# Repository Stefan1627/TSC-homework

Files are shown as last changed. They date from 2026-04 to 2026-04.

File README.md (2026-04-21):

# TSC-homework - Stefan Calmac 334CC
# InkTime Watch

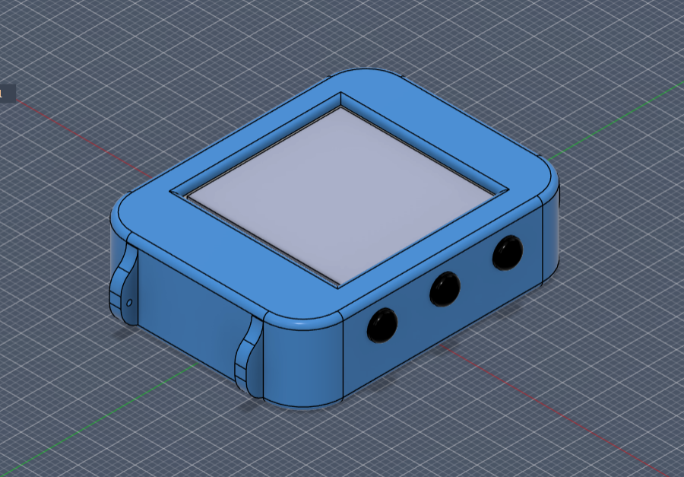
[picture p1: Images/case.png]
InkTime Watch 3D Render


---

## Block Diagram

```
           [ USB Type-C ]                              [ LiPo Battery (250mAh) ]
                 | 5V VBUS                                      |
                 v                                              |
          +---------------+                                     |
          |               | BAT                                 |
          |    BQ25180    |<------------------------------------+
          | (Charger IC)  |                                     |
          +---------------+                                     v
                 | VSYS                                 +---------------+
                 v                                      |   MAX17048    |
          +---------------+                             | (Fuel Gauge)  |
          |    RT6160     |                             +---------------+
          | (Buck-Boost)  |                                     ^
          +---------------+                                     |
                 | 3.3V System Rail (VDD_3V3)                   |
                 |                                              |
 +---------------+----------------------------------------------+-----+
 |               |                                              |     |
 |               v                                              |     |
 |        +-------------+         I2C Bus                       |     |
 |        |             |<======================================+     |
 |        |             |                                             |
 |        |             |=== I2C ===> [ BMA421 Accelerometer ]        |
 |        |  nRF52840   |                                             |
 |        |    MCU      |=== I2C ===> [ DRV2605L Driver ]-->[ Motor ] |
 |        |             |                                             |
 |        |             |=== SPI ===> [ 1.54" E-paper Display ]       |
 |        |             |                       ^                     |
 |        |             |-- GPIO (Gate)         | VEPD (Switched Pwr) |
 |        +-------------+      |                |                     |
 |          ^  ^  ^  |         v                |                     |
 |          |  |  |  | +---------------+        |                     |
 +---------(|--|--|)-+-|  PFET Switch  |--------+                     |
            |  |  |  | +---------------+                              |
 [Up]-------+  |  |  |                                                |
           [Down] |  +--- [ 2.4GHz Antenna ] - - - BLE - - - [ Companion ]
                  |                                          [   Phone   ]
              [Enter/Esc]
```

---

## Bill of Materials (BOM)

Below is the list of primary active and critical passive components used in this
design. Links are provided to JLCPCB parts (LCSC) and standard datasheets.

| Component / Module | Description | Package / Footprint | Part | Datasheet Link |
:--- | :--- | :--- | :--- | :--- |
| **nRF52840** | Multi-protocol BLE 5.0 Cortex-M4F MCU | AQFN-73 | [C190794](https://jlcpcb.com/partdetail/NordicSemicon-NRF52840_QIAAR/C190794) | [Nordic nRF52840](https://www.nordicsemi.com/Products/nRF52840) |
| **BQ25180YBGR** | I2C Controlled 1A Linear LiPo Charger | DSBGA-8 | [BQ25180YBGR](https://www.ti.com/product/BQ25180/part-details/BQ25180YBGR) | [TI BQ25180](https://www.ti.com/product/BQ25180) |
| **MAX17048G+T10** | Micropower 1-Cell Fuel Gauge | TDFN-8 | [C2682616](https://www.lcsc.com/product-detail/C2682616.html) | [Maxim MAX17048](https://www.analog.com/en/products/max17048.html) |
| **RT6160AWSC** | High-Efficiency Buck-Boost Converter (3.3V) | WLCSP-15 | [C7065276](https://www.lcsc.com/product-detail/C7065276.html) | [Richtek RT6160A](https://www.richtek.com/assets/product_file/RT6160A/DS6160A-02.pdf) |
| **BMA421** | Ultra-Low Power IMU / Step Counter | LGA-12 | [C5242966](https://jlcpcb.com/partdetail/BoschSensortec-BMA421/C5242966) | [Bosch BMA421](https://www.bosch-sensortec.com/products/motion-sensors/imus/bma421/) |
| **DRV2605YZFR** | Haptic Driver for LRA/ERM | DSBGA-9 | [C527464](https://jlcpcb.com/partdetail/C527464) | [TI DRV2605](https://www.ti.com/product/DRV2605) |
| **2450AT18B100E** | 2.4GHz Chip Antenna | 1206 | [C2917717](https://jlcpcb.com/partdetail/JohansonDielectrics-2450AT18B100E/C2917717) | [Johanson 2450AT18B100E](https://www.johansontechnology.com/datasheets/antennas/2450AT18B100.pdf) |
| **USBLC6-2SC6Y** | Very low capacitance ESD protection | SOT-23-6 | [C2969755](https://jlcpcb.com/partdetail/STMicroelectronics-USBLC62SC6Y/C2969755) | [ST USBLC6-2](https://www.st.com/resource/en/datasheet/usblc6-2.pdf) |
| **KH-TYPE-C-16P** | USB Type-C 16-Pin Receptacle | SMD | [C168704](https://jlcpcb.com/partdetail/180087-918418K2022Y40000/C168704) | [Generic USB-C](https://datasheet.lcsc.com/lcsc/1811151641_Korean-Hroparts-Elec-TYPE-C-31-M-12_C165948.pdf) |
| **503480-2400** | 24-Pin FPC Connector (0.5mm pitch) for EPD | SMD |  | [Molex 503480](https://www.molex.com/molex/products/part-detail/ffc_fpc_connectors/5034802400) |
| **DMG2305UX** | P-Channel MOSFET (EPD Power Control) | SOT-23 | [C2940629](https://jlcpcb.com/partdetail/TECHPUBLIC-DMG2305UX/C2940629) | [Diodes DMG2305](https://www.diodes.com/assets/Datasheets/DMG2305UX.pdf) |
| **MBR0530** | Schottky Diode (E-Paper Pump Circuit) | SOD-123 | [C77336](https://jlcpcb.com/partdetail/78464-MBR0530/C77336) | [Onsemi MBR0530](https://www.onsemi.com/pdf/datasheet/mbr0530t1-d.pdf) |
| **TC2030-IDC** | 6-Pin Tag-Connect SWD Interface | PCB Footprint | [Tag-Connect](https://www.tag-connect.com/product/tc2030-idc-nl) | [Tag-Connect TC2030](https://www.tag-connect.com/product/tc2030-idc-6-pin-tag-connect-plug-of-nails-spring-pin-cable-with-ribbon-connector) |

### Passive Components

| Component | Value | Package | Qty | Function |
|---|---|---|-----|---|
| Capacitors (decoupling) | 100nF | 0201 | 5 | MCU + peripheral decoupling |
| Capacitors (crystal load) | 12pF | 0201 | 4 | 32MHz + 32.768kHz crystal loads |
| Capacitors (bulk) | 4.7uF | 0402 | 4 | MCU power rail bulk decoupling |
| Capacitors (USB) | 4.7uF | 0402 | 1 | DECUSB capacitor |
| Capacitors (power) | 22uF | 0402 | 2 | RT6160 input capacitors |
| Capacitors (charger) | 1uF | 0402 | 3 | BQ25180 CIN/CSYS/CBAT |
| Capacitors (EPD) | 1uF/50V | 0402 | 9 | E-paper driver capacitors |
| Inductor (DC/DC) | 10uH | 0402 | 1 | nRF52840 REG1 DC/DC inductor |
| Inductor (buck-boost) | 0.47uH | 2012 | 1 | RT6160 power stage inductor |
| Resistors (I2C pull-up) | 10k | 0201 | 2 | I2C SDA/SCL pull-ups |
| Resistors (USB CC) | 5.1k | 0201 | 2 | USB Type-C CC1/CC2 pull-downs |
| Crystals | 32 MHz | 2016 | 1 | HFXO for MCU + radio |
| Crystals | 32.768 kHz | 3215 | 1 | LFXO for RTC timekeeping |

---

## Hardware Description

### MCU - nRF52840

The nRF52840 is the central processing unit of InkTime. It integrates:

- **ARM Cortex-M4F** at 64 MHz with FPU
- **BLE 5.0** (used for time sync, notifications)
- **USB 2.0 Full Speed** (charging detection and firmware updates)
- **1 MB Flash / 256 KB RAM**

All peripherals are connected directly to the nRF52840 via SPI (e-paper display) and I2C (IMU, fuel gauge, haptic driver, PMIC).

### Power Path

```
USB-C --> BQ25180 (charger) --> LiPo battery (AKY0106, 400 mAh)
                            --> 3.3V rail (VREG, for MCU and all peripherals)
Battery --> RT6160AWSC (boost) --> EPD high-voltage supply (VCOM, gate voltages)
```

- **BQ25180YBGR** manages LiPo charging at up to 1A, monitors VBUS, and raises `PMIC_INT` for fault/status events. Communicates with the MCU over I2C.
- **RT6160AWSC** is a boost converter that generates the higher voltages needed by the e-paper display driver (PREVGH, PREVGL, etc.).
- **MAX17048G+T10** is a ModelGauge fuel gauge that estimates battery state-of-charge (SOC) with 1% accuracy over I2C, using a single-cell LiPo model.

### E-Paper Display - WSH-12561

The e-paper display connects to the MCU over **SPI** plus 3 control GPIOs:

| Signal | Direction | Description |
| --- | --- | --- |
| SCK | MCU → EPD | SPI clock |
| MOSI | MCU → EPD | SPI data |
| EPD_CS | MCU → EPD | Chip select (active low) |
| EPD_DC | MCU → EPD | Data / Command select |
| EPD_RST  | MCU → EPD | Hardware reset (active low) |
| EPD_BUSY | EPD → MCU | Busy flag (MCU must wait) |

The EPD drive circuit (biased by RT6160AWSC) generates the voltages PREVGH, PREVGL, PREVGL, GDR necessary to drive the e-paper panel.

### IMU

6-axis inertial measurement unit connected via **I2C** at 400 kHz. Provides:

- 3-axis accelerometer (step counting, gesture detection, orientation)
- 3-axis gyroscope (motion tracking)
- Two interrupt lines (`IMU_INT1`, `IMU_INT2`) for wake-on-motion and data-ready events

### Haptic Feedback - DRV2605 + FIT0774

The DRV2605YZFR haptic driver controls the FIT0774 ERM motor. It connects to the MCU over **I2C** and has a digital enable signal `HAPTIC_EN`. It supports library-based waveform playback (124 built-in effects).

### USB - KH-TYPE-C-16P + USBLC6-2SC6Y

USB-C connector with USBLC6-2SC6Y ESD protection on D+ and D− lines. The MCU detects VBUS presence via a GPIO for charging control handoff. USB D+ / D− connect directly to the nRF52840's USB transceiver.

### Antenna - 2450AT18B100E

2.4 GHz chip antenna placed at the PCB edge, away from metal and ground planes. The PCB is **cutout under the antenna** - no copper pours or signal traces are routed under the antenna keepout area. Impedance matching network (L + C pi filter) is present between the nRF52840 RF pin and the antenna.

### SWD Debug - TC2030-IDC

Tag-Connect TC2030-IDC footprint for in-circuit programming and debugging (no connector needed, uses spring-loaded probe). Test pads TP_SWDIO, TP_SWDCLK, TP_RESET, TP_3.3V, TP_GND are exposed on the PCB silkscreen.

---

## nRF52840 Pinout Specification
The major hardware peripherals are mapped to the MCU as follows:

*   **Shared I2C Bus (with 10k pull-ups to 3.3V):**
    *   `P0.06` - SDA (Data for BMA421, MAX17048, BQ25180, RT6160, DRV2605L).
    *   `P0.07` - SCL (Clock).
*   **SPI Bus (E-paper Display):**
    *   `P0.02` - SCK
    *   `P0.03` - MOSI
    *   `P0.05` - CS (Chip Select)
    *   `P0.15` - DC (Data/Command)
    *   `P0.16` - RST (Reset)
    *   `P0.17` - BUSY (Panel status)
    *   `P1.01` - PFET Gate (Enables/disables the display power rail)
*   **Interrupts & Peripherals:**
    *   `P0.08` - BMA421 INT1 (Primary motion/step wake).
    *   `P1.08` - BMA421 INT2 (Secondary motion events).
    *   `P0.10` - MAX17048 ALRT (Low battery wake).
    *   `P0.11` - BQ25180 /INT (Charger state wake).
    *   `P0.12` - DRV2605L EN (Enable haptics chip).
*   **Physical Buttons (Active-low to GND):**
    *   `P0.13` - Up Button.
    *   `P0.14` - Down Button.
    *   `P1.00` - Enter / Esc Button.
*   **Debug & Clocks:**
    *   `XC1/XC2` & `XL1/XL2` - Connects the 32MHz and 32.768kHz external crystals.
    *   `SWDIO`, `SWDCLK`, `nRESET` - Connected to the Tag-Connect TC2030 debug footprint.

--- 

## PCB Design

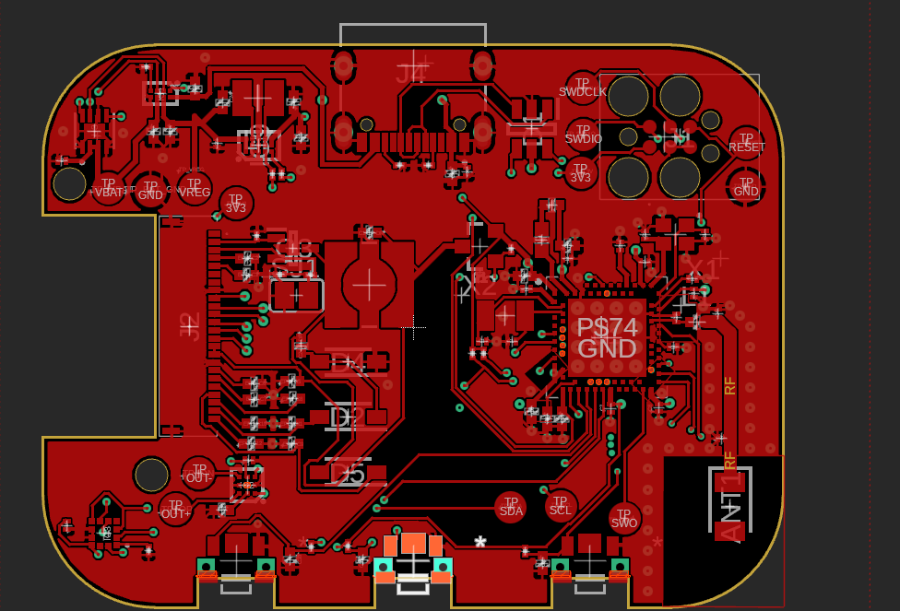
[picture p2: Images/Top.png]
Top layer


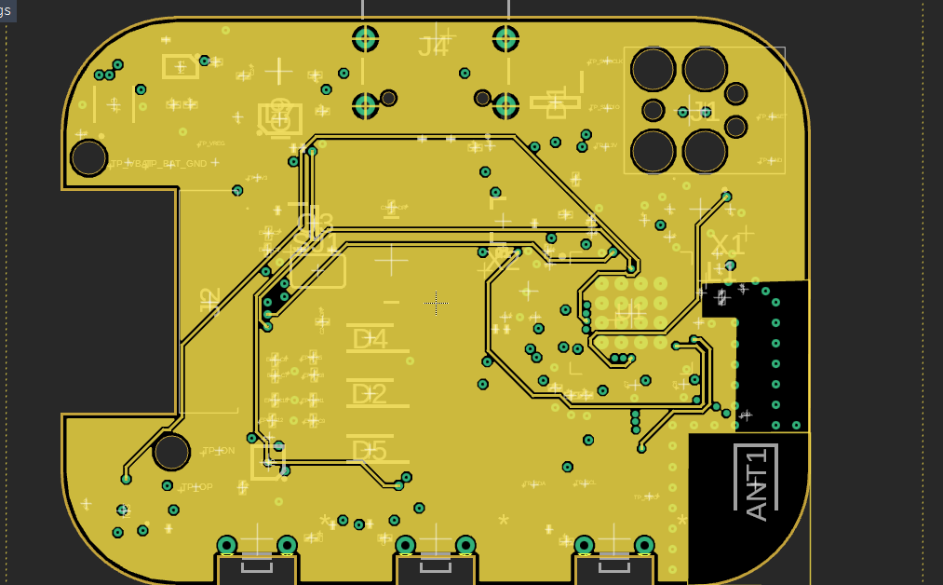
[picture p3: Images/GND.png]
Middle_1 layer


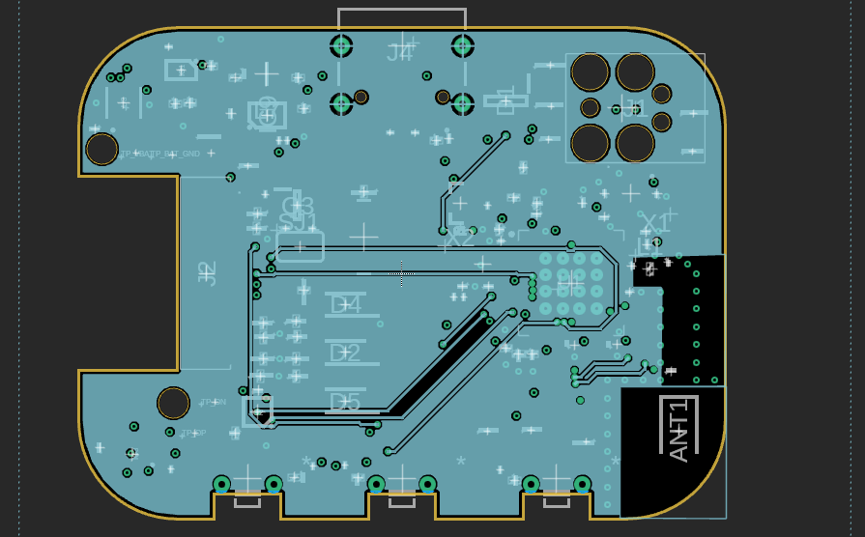
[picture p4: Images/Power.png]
Middle_2 layer


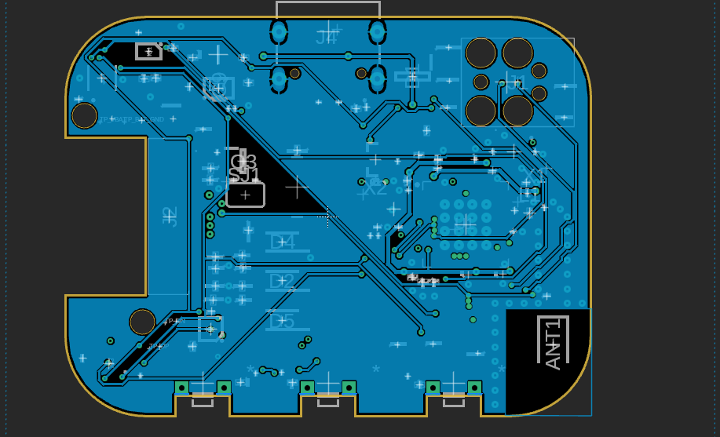
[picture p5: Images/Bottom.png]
Bottom layer


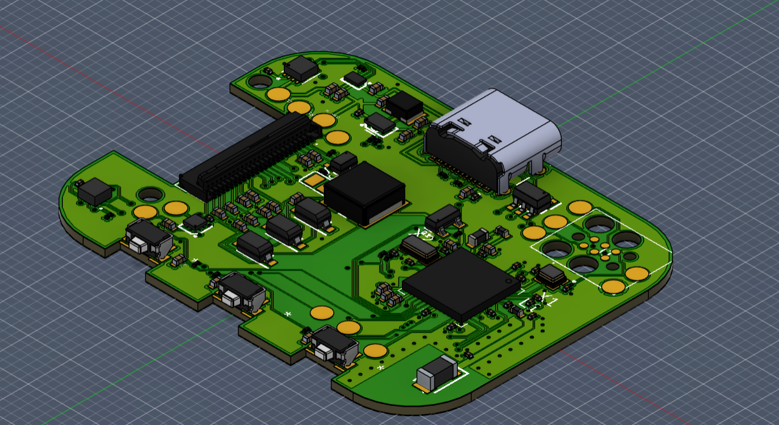
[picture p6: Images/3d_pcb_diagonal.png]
3D Pcb


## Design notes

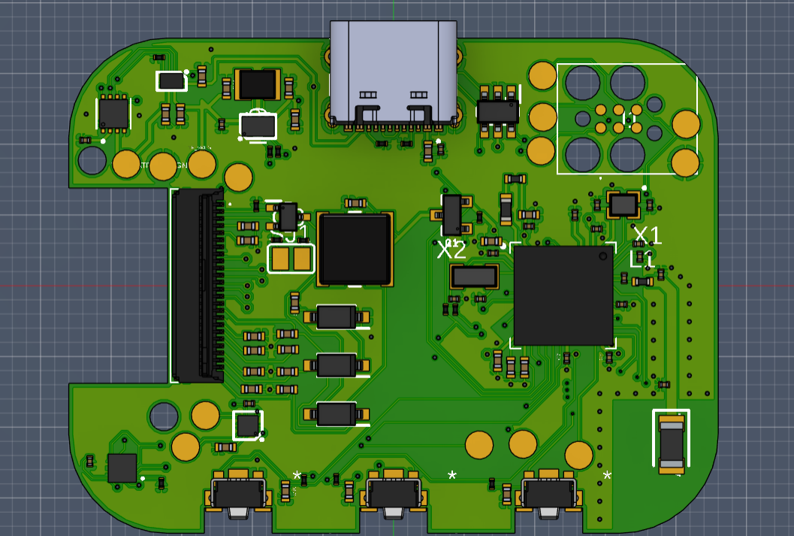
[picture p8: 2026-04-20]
Images/3d_pcb_top.png

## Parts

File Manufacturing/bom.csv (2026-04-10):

Part | Value | Device | Footprint Name | Detailed Description | ARROW_PART_NUMBER | ARROW_PRICE-STOCK | AVAILABILITY | CHECK_PRICES | COPYRIGHT | DESCRIPTION | DIGI-KEY_PART_NUMBER_1 | DIGI-KEY_PART_NUMBER_2 | DIGI-KEY_PART_NUMBER_3 | HEIGHT | JLCPCB | MANUFACTURER_NAME | MANUFACTURER_PART_NUMBER | MF | MFR_NAME | MOUSER_PART_NUMBER | MOUSER_PRICE-STOCK | MP | PACKAGE | POPULARITY | PRICE | PROD_ID | PURCHASE-URL | SNAPEDA_LINK | TP_SIGNAL_NAME | VALUE
ANT1 | 2450AT18B100E | 2450AT18B100E_2450AT18B100E | 2450AT18B100E_ANTC3216X140N | Antennas 2.45GHz ANTENNA | 2450AT18B100E | https://www.arrow.com/en/products/2450at18b100e/johanson-dielectrics?utm_currency=USD&region=nac |  |  |  | Antennas 2.45GHz ANTENNA |  |  |  | 1.4mm |  | JOHANSON TECHNOLOGY | 2450AT18B100E |  |  | 609-2450AT18B100E | https://www.mouser.co.uk/ProductDetail/Johanson-Technology/2450AT18B100E?qs=yCnrNFeXz%252Bh5MFsFIXGZGA%3D%3D
C1 | 12pF | NORDIC_NRF_3_CAPACITOR_0201_L | NORDIC_NRF_3_RESC0201_L | Generic chip capacitor
C1-EP-DR | 10uF | NORDIC_NRF_3_CAPACITOR_0402_L | NORDIC_NRF_3_RESC0402_L | Generic chip capacitor
C2-EP-DR | 4.7uF/25V | NORDIC_NRF_3_CAPACITOR_0402_L | NORDIC_NRF_3_RESC0402_L | Generic chip capacitor
C3 | 1pF | NORDIC_NRF_3_CAPACITOR_0201_L | NORDIC_NRF_3_RESC0201_L | Generic chip capacitor
C4 | 1pF | NORDIC_NRF_3_CAPACITOR_0201_L | NORDIC_NRF_3_RESC0201_L | Generic chip capacitor
C5 | 100nF | NORDIC_NRF_3_CAPACITOR_0201_L | NORDIC_NRF_3_RESC0201_L | Generic chip capacitor
C6 | 4.7uF | NORDIC_NRF_3_CAPACITOR_0402_L | NORDIC_NRF_3_RESC0402_L | Generic chip capacitor
C7 | 100nF | NORDIC_NRF_3_CAPACITOR_0201_L | NORDIC_NRF_3_RESC0201_L | Generic chip capacitor
C8 | 100nF | NORDIC_NRF_3_CAPACITOR_0201_L | NORDIC_NRF_3_RESC0201_L | Generic chip capacitor
C9 | 820pF | NORDIC_NRF_3_CAPACITOR_0201_L | NORDIC_NRF_3_RESC0201_L | Generic chip capacitor
C10 | N.C. | NORDIC_NRF_3_CAPACITOR_0201_L | NORDIC_NRF_3_RESC0201_L | Generic chip capacitor
C11 | 100pF | NORDIC_NRF_3_CAPACITOR_0201_L | NORDIC_NRF_3_RESC0201_L | Generic chip capacitor
C12 | 100nF | NORDIC_NRF_3_CAPACITOR_0201_L | NORDIC_NRF_3_RESC0201_L | Generic chip capacitor
C13 | N.C. | NORDIC_NRF_3_CAPACITOR_0201_L | NORDIC_NRF_3_RESC0201_L | Generic chip capacitor
C14 | 4.7uF | NORDIC_NRF_3_CAPACITOR_0402_L | NORDIC_NRF_3_RESC0402_L | Generic chip capacitor
C15 | 1.0uF | NORDIC_NRF_3_CAPACITOR_0402_L | NORDIC_NRF_3_RESC0402_L | Generic chip capacitor
C16 | 47nF | NORDIC_NRF_3_CAPACITOR_0201_L | NORDIC_NRF_3_RESC0201_L | Generic chip capacitor
C17 | 12pF | NORDIC_NRF_3_CAPACITOR_0201_L | NORDIC_NRF_3_RESC0201_L | Generic chip capacitor
C18 | 12pF | NORDIC_NRF_3_CAPACITOR_0201_L | NORDIC_NRF_3_RESC0201_L | Generic chip capacitor
C19 | 100nF | NORDIC_NRF_3_CAPACITOR_0201_L | NORDIC_NRF_3_RESC0201_L | Generic chip capacitor
C20\ | 4.7uF | NORDIC_NRF_3_CAPACITOR_0402_L | NORDIC_NRF_3_RESC0402_L | Generic chip capacitor
C21 | 4.7uF | NORDIC_NRF_3_CAPACITOR_0402_L | NORDIC_NRF_3_RESC0402_L | Generic chip capacitor
C22 | N.C. | NORDIC_NRF_3_CAPACITOR_0201_L | NORDIC_NRF_3_RESC0201_L | Generic chip capacitor
C23 | 0.1uF | NORDIC_NRF_3_CAPACITOR_0201_L | NORDIC_NRF_3_RESC0201_L | Generic chip capacitor
C24 | 10uF | NORDIC_NRF_3_CAPACITOR_0402_L | NORDIC_NRF_3_RESC0402_L | Generic chip capacitor
C25 | 22uF | NORDIC_NRF_3_CAPACITOR_0402_L | NORDIC_NRF_3_RESC0402_L | Generic chip capacitor
C27 | 0.1uF | NORDIC_NRF_3_CAPACITOR_0201_L | NORDIC_NRF_3_RESC0201_L | Generic chip capacitor
C29 | 1uF | NORDIC_NRF_3_CAPACITOR_0402_L | NORDIC_NRF_3_RESC0402_L | Generic chip capacitor
C30 | 1uF | NORDIC_NRF_3_CAPACITOR_0402_L | NORDIC_NRF_3_RESC0402_L | Generic chip capacitor
C31 | 1uF | NORDIC_NRF_3_CAPACITOR_0402_L | NORDIC_NRF_3_RESC0402_L | Generic chip capacitor
C32 | 1uF | NORDIC_NRF_3_CAPACITOR_0402_L | NORDIC_NRF_3_RESC0402_L | Generic chip capacitor
C33 | 22uF | NORDIC_NRF_3_CAPACITOR_0402_L | NORDIC_NRF_3_RESC0402_L | Generic chip capacitor
C34 | 0.1uF | NORDIC_NRF_3_CAPACITOR_0201_L | NORDIC_NRF_3_RESC0201_L | Generic chip capacitor
C37 | 1uF | NORDIC_NRF_3_CAPACITOR_0402_L | NORDIC_NRF_3_RESC0402_L | Generic chip capacitor
C38 | 1uF | NORDIC_NRF_3_CAPACITOR_0402_L | NORDIC_NRF_3_RESC0402_L | Generic chip capacitor
C39 | 10uF | NORDIC_NRF_3_CAPACITOR_0402_L | NORDIC_NRF_3_RESC0402_L | Generic chip capacitor
C42 | 0.1uF | NORDIC_NRF_3_CAPACITOR_0201_L | NORDIC_NRF_3_RESC0201_L | Generic chip capacitor
C43 | 4.7uF | NORDIC_NRF_3_CAPACITOR_0402_L | NORDIC_NRF_3_RESC0402_L | Generic chip capacitor
D1 | USBLC6-2SC6Y | USBLC6-2SC6Y | SOT95P280X145-6N | Low Cap. ESD Protection Auto SOT-23-6 STMicroelectronics USBLC6-2SC6Y, Dual Uni-Directional TVS Diode Array, 6-Pin SOT-23 | USBLC6-2SC6Y | https://www.arrow.com/en/products/usblc6-2sc6y/stmicroelectronics?utm_currency=USD&region=nac |  |  |  | Low Cap. ESD Protection Auto SOT-23-6 STMicroelectronics USBLC6-2SC6Y, Dual Uni-Directional TVS Diode Array, 6-Pin SOT-23 |  |  |  | 1.45mm |  | STMicroelectronics | USBLC6-2SC6Y |  |  | 511-USBLC6-2SC6Y | https://www.mouser.co.uk/ProductDetail/STMicroelectronics/USBLC6-2SC6Y?qs=gNDSiZmRJS%2FOgDexvXkdow%3D%3D
D2 | MBR0530 | ESP32_C6_LIBRARY_5_MBR0530 | ESP32_C6_LIBRARY_5_SOD3716X135N | ON SEMICONDUCTOR - MBR0530 - DIODE, SCHOTTKY, 0.5A, 30V, SOD-123 |  |  | In Stock | https://www.snapeda.com/parts/MBR0530/Onsemi/view-part/?ref=eda |  | Diode Schottky 30 V 500mA Surface Mount SOD-123 |  |  |  |  |  |  |  | ON Semiconductor |  |  |  | MBR0530 | SOD-123-2 ON Semiconductor |  | None |  | https://www.snapeda.com/api/url_track_click_mouser/?unipart_id=179458&manufacturer=ON Semiconductor&part_name=MBR0530&search_term=None | https://www.snapeda.com/parts/MBR0530/Onsemi/view-part/?ref=snap
D4 | MBR0530 | ESP32_C6_LIBRARY_5_MBR0530 | ESP32_C6_LIBRARY_5_SOD3716X135N | ON SEMICONDUCTOR - MBR0530 - DIODE, SCHOTTKY, 0.5A, 30V, SOD-123 |  |  | In Stock | https://www.snapeda.com/parts/MBR0530/Onsemi/view-part/?ref=eda |  | Diode Schottky 30 V 500mA Surface Mount SOD-123 |  |  |  |  |  |  |  | ON Semiconductor |  |  |  | MBR0530 | SOD-123-2 ON Semiconductor |  | None |  | https://www.snapeda.com/api/url_track_click_mouser/?unipart_id=179458&manufacturer=ON Semiconductor&part_name=MBR0530&search_term=None | https://www.snapeda.com/parts/MBR0530/Onsemi/view-part/?ref=snap
D5 | MBR0530 | ESP32_C6_LIBRARY_5_MBR0530 | ESP32_C6_LIBRARY_5_SOD3716X135N | ON SEMICONDUCTOR - MBR0530 - DIODE, SCHOTTKY, 0.5A, 30V, SOD-123 |  |  | In Stock | https://www.snapeda.com/parts/MBR0530/Onsemi/view-part/?ref=eda |  | Diode Schottky 30 V 500mA Surface Mount SOD-123 |  |  |  |  |  |  |  | ON Semiconductor |  |  |  | MBR0530 | SOD-123-2 ON Semiconductor |  | None |  | https://www.snapeda.com/api/url_track_click_mouser/?unipart_id=179458&manufacturer=ON Semiconductor&part_name=MBR0530&search_term=None | https://www.snapeda.com/parts/MBR0530/Onsemi/view-part/?ref=snap
EPD_C1 | 1uF/50V | NORDIC_NRF_3_CAPACITOR_0402_L | NORDIC_NRF_3_RESC0402_L | Generic chip capacitor
EPD_C2 | 1uF/50V | NORDIC_NRF_3_CAPACITOR_0402_L | NORDIC_NRF_3_RESC0402_L | Generic chip capacitor
EPD_C5 | 0.1uF/50V | NORDIC_NRF_3_CAPACITOR_0201_L | NORDIC_NRF_3_RESC0201_L | Generic chip capacitor
EPD_C6 | 1uF/50V | NORDIC_NRF_3_CAPACITOR_0402_L | NORDIC_NRF_3_RESC0402_L | Generic chip capacitor
EPD_C7 | 1uF/50V | NORDIC_NRF_3_CAPACITOR_0402_L | NORDIC_NRF_3_RESC0402_L | Generic chip capacitor
EPD_C8 | 1uF/50V | NORDIC_NRF_3_CAPACITOR_0402_L | NORDIC_NRF_3_RESC0402_L | Generic chip capacitor
EPD_C9 | 1uF/50V | NORDIC_NRF_3_CAPACITOR_0402_L | NORDIC_NRF_3_RESC0402_L | Generic chip capacitor
EPD_C10 | 1uF/50V | NORDIC_NRF_3_CAPACITOR_0402_L | NORDIC_NRF_3_RESC0402_L | Generic chip capacitor
EPD_C11 | 1uF/50V | NORDIC_NRF_3_CAPACITOR_0402_L | NORDIC_NRF_3_RESC0402_L | Generic chip capacitor
EPD_C12 | 1uF/50V | NORDIC_NRF_3_CAPACITOR_0402_L | NORDIC_NRF_3_RESC0402_L | Generic chip capacitor
IC1 | BQ25180YBGR_BQ25180YBGR | BQ25180YBGR_BQ25180YBGR | BQ25180YBGR_BGA8C40P2X4_100X155X50 | Charger IC Lithium Ion/Polymer, Lithium Iron Phosphate 8-DSBGA (1.6x1.1) | BQ25180YBGR | https://www.arrow.com/en/products/bq25180ybgr/texas-instruments?utm_currency=USD&region=nac |  |  |  | Charger IC Lithium Ion/Polymer, Lithium Iron Phosphate 8-DSBGA (1.6x1.1) |  |  |  | 0.5mm |  | Texas Instruments | BQ25180YBGR |  |  | 595-BQ25180YBGR | https://www.mouser.co.uk/ProductDetail/Texas-Instruments/BQ25180YBGR?qs=doiCPypUmgEWjAK%252BJAX6Tw%3D%3D
IC2 | DRV2605YZFR | DRV2605YZFR_DRV2605YZFR | DRV2605YZFR_BGA9C50P3X3_144X144X62 | Haptic Driver for ERM/LRA with Built-In Library and Smart Loop Architecture | DRV2605YZFR | https://www.arrow.com/en/products/drv2605yzfr/texas-instruments?region=nac |  |  |  | Haptic Driver for ERM/LRA with Built-In Library and Smart Loop Architecture |  |  |  | 0.625mm |  | Texas Instruments | DRV2605YZFR
IC3 | BMA423 | BMA423_BMA423 | BMA423_BMA423 | Accelerometers Triaxial low-g 12bit Acceleration Sensor | BMA423 | https://www.arrow.com/en/products/bma423/bosch |  |  |  | Accelerometers Triaxial low-g 12bit Acceleration Sensor |  |  |  | 1mm |  | BOSCH | BMA423 |  |  | 262-BMA423 | https://www.mouser.co.uk/ProductDetail/Bosch-Sensortec/BMA423?qs=HXFqYaX1Q2xC%252BSgeGoX3mg%3D%3D
IC9 | RT6160AWSC | RT6160AWSC_RT6160AWSC | RT6160AWSC_BGA15C40P3X5_140X230X60 | Buck-Boost Regulator Positive Output Step-Up/Step-Down I2C DC-DC Controller IC 15-WL-CSP (BSC) (1.4x2.3) |  |  |  |  |  | Buck-Boost Regulator Positive Output Step-Up/Step-Down I2C DC-DC Controller IC 15-WL-CSP (BSC) (1.4x2.3) |  |  |  | 0.6mm |  | RICHTEK | RT6160AWSC |  |  | 835-RT6160AWSC | https://www.mouser.co.uk/ProductDetail/Richtek/RT6160AWSC?qs=amGC7iS6iy%2FLd9PSoixZXQ%3D%3D
J1 | TC2030-IDC | TC2030-IDC_TC2030-IDC | TC2030-IDC_TC2030IDC | CABLE ADAPTER 6 POS |  |  |  |  |  | CABLE ADAPTER 6 POS |  |  |  | 19mm |  | Tag Connect | TC2030-IDC
J2 | 503480-2400 | 503480-2400_503480-2400 | 503480-2400_5034802400 | FFC & FPC Connectors 0.5mm FPC RA SMT Dual Contact 24Ckt |  |  |  |  |  | FFC & FPC Connectors 0.5mm FPC RA SMT Dual Contact 24Ckt |  |  |  | 1.87mm |  | Molex | 503480-2400 |  |  | 538-503480-2400 | https://www.mouser.co.uk/ProductDetail/Molex/503480-2400?qs=OAhjpuo3Vu7efIoxFh9AOw%3D%3D
J4 | KH-TYPE-C-16P | KH-TYPE-C-16P_KH-TYPE-C-16P | KH-TYPE-C-16P_KINGHELM_KH-TYPE-C-16P | Check availability |  |  | Not in stock | https://www.snapeda.com/parts/KH-TYPE-C-16P/Kinghelm/view-part/?ref=eda |  |  |  |  |  |  |  |  |  | kinghelm |  |  |  | KH-TYPE-C-16P | None |  | None |  |  | https://www.snapeda.com/parts/KH-TYPE-C-16P/Kinghelm/view-part/?ref=snap
L1 | 3.9nH | NORDIC_NRF_2_INDUCTOR_0402_L | NORDIC_NRF_2_RESC0402_L | Generic chip inductor
L2 | 10uH | NORDIC_NRF_2_INDUCTOR_0402_L | NORDIC_NRF_2_RESC0402_L | Generic chip inductor
L3 | 15nH | NORDIC_NRF_2_INDUCTOR_0402_L | NORDIC_NRF_2_RESC0402_L | Generic chip inductor
L5 | 68uH | ESP32_C6_LIBRARY_2_744043680IND_4828-WE-TPC_WRE | ESP32_C6_LIBRARY_2_IND_4828-WE-TPC_WRE |  |  |  |  |  | Copyright (C) 2024 Ultra Librarian. All rights reserved. |  |  |  |  |  |  |  | 744043680 |  | Wurth Electronics
L7 | FTC252012SR47MBCA | MLP2016SR47MT0S1_FTC252012SR47MBCA | MLP2016SR47MT0S1_INDC2016X100N | SMD / SMT Inductors (Coils), L=0.47?H, L x W x T : |  |  |  |  |  | SMD / SMT Inductors (Coils), L=0.47?H, L x W x T : |  |  |  | 1mm | https://jlcpcb.com/partdetail/6763488-FTC252012SR47MBCA/C5832368 | TDK | FTC252012SR47MBCA
Q1 | 20V/4.2A/52mO/1.4W | ESP32_C6_LIBRARY_4_ESP32_WROVER_SPARKFUN-DISCRETESEMI_MOSFET_PCH-DMG2305UX-7 | ESP32_C6_LIBRARY_4_ESP32_C6_LIBRARY_4_ESP32_C6_LIBRARY_4_ESP32_C6_LIBRARY_4_ESP32_WROVER_SPARKFUN-DISCRETESEMI_SOT23-3 | P-channel MOSFETs |  |  |  |  |  |  |  |  |  |  |  |  |  |  |  |  |  |  |  |  |  | TRAN-14388 |  |  |  | 20V/4.2A/52mO/1.4W
Q3 | SI1308EDL-T1-GE3 | ESP32_C6_LIBRARY_6_SI1308EDL-T1-GE3 | ESP32_C6_LIBRARY_6_SOT65P210X110-3N | MOSFET N-Ch 30V 1.5A TrenchFET SC70 Vishay Si1308EDL-T1-GE3 N-channel MOSFET Transistor, 1.5 A, 30 V, 3-Pin SC-70 |  |  | In Stock | https://www.snapeda.com/parts/SI1308EDL-T1-GE3/Vishay+Siliconix/view-part/?ref=eda |  | Si1308EDL-T1-GE3 N-channel MOSFET Transistor, 1.5 A, 30 V, 3-Pin SC-70 | Siliconix / Vishay SI1308EDL-T1-GE3 |  |  |  |  |  |  |  | Vishay Siliconix |  |  |  | SI1308EDL-T1-GE3 | SOT-323 Vishay Semiconductor |  | None |  | https://www.snapeda.com/api/url_track_click_mouser/?unipart_id=274603&manufacturer=Vishay Siliconix&part_name=SI1308EDL-T1-GE3&search_term=None | https://www.snapeda.com/parts/SI1308EDL-T1-GE3/Vishay+Siliconix/view-part/?ref=snap
R1_EP_DR | 0.47 | CPF0201D7K68C1_CPF0201D7K68C1 | CPF0201D7K68C1_0201 | 7.68k 0201 Thin Film Surface Mount Fixed Resistor +/-0.5% 0.031W CPF0201D7K68C1
R1_USB | 5K1 | CPF0201D7K68C1_CPF0201D7K68C1 | CPF0201D7K68C1_0201 | 7.68k 0201 Thin Film Surface Mount Fixed Resistor +/-0.5% 0.031W CPF0201D7K68C1
R2 | 0 | CPF0201D7K68C1_CPF0201D7K68C1 | CPF0201D7K68C1_0201 | 7.68k 0201 Thin Film Surface Mount Fixed Resistor +/-0.5% 0.031W CPF0201D7K68C1
R2_EP_DR | 10K | CPF0201D7K68C1_CPF0201D7K68C1 | CPF0201D7K68C1_0201 | 7.68k 0201 Thin Film Surface Mount Fixed Resistor +/-0.5% 0.031W CPF0201D7K68C1
R2_USB | 5K1 | CPF0201D7K68C1_CPF0201D7K68C1 | CPF0201D7K68C1_0201 | 7.68k 0201 Thin Film Surface Mount Fixed Resistor +/-0.5% 0.031W CPF0201D7K68C1
R3 | 0 | CPF0201D7K68C1_CPF0201D7K68C1 | CPF0201D7K68C1_0201 | 7.68k 0201 Thin Film Surface Mount Fixed Resistor +/-0.5% 0.031W CPF0201D7K68C1
R4 | 0 | CPF0201D7K68C1_CPF0201D7K68C1 | CPF0201D7K68C1_0201 | 7.68k 0201 Thin Film Surface Mount Fixed Resistor +/-0.5% 0.031W CPF0201D7K68C1
R5 | 10K | CPF0201D7K68C1_CPF0201D7K68C1 | CPF0201D7K68C1_0201 | 7.68k 0201 Thin Film Surface Mount Fixed Resistor +/-0.5% 0.031W CPF0201D7K68C1
R7 | 10K | CPF0201D7K68C1_CPF0201D7K68C1 | CPF0201D7K68C1_0201 | 7.68k 0201 Thin Film Surface Mount Fixed Resistor +/-0.5% 0.031W CPF0201D7K68C1
R8 | 10K | CPF0201D7K68C1_CPF0201D7K68C1 | CPF0201D7K68C1_0201 | 7.68k 0201 Thin Film Surface Mount Fixed Resistor +/-0.5% 0.031W CPF0201D7K68C1
R9 | 10K | CPF0201D7K68C1_CPF0201D7K68C1 | CPF0201D7K68C1_0201 | 7.68k 0201 Thin Film Surface Mount Fixed Resistor +/-0.5% 0.031W CPF0201D7K68C1
R17 | 3K3 | CPF0201D7K68C1_CPF0201D7K68C1 | CPF0201D7K68C1_0201 | 7.68k 0201 Thin Film Surface Mount Fixed Resistor +/-0.5% 0.031W CPF0201D7K68C1
R18 | 3K3 | CPF0201D7K68C1_CPF0201D7K68C1 | CPF0201D7K68C1_0201 | 7.68k 0201 Thin Film Surface Mount Fixed Resistor +/-0.5% 0.031W CPF0201D7K68C1
R_PWR_EDP | 10K | CPF0201D7K68C1_CPF0201D7K68C1 | CPF0201D7K68C1_0201 | 7.68k 0201 Thin Film Surface Mount Fixed Resistor +/-0.5% 0.031W CPF0201D7K68C1
R_TYPE_SEL | 2.2 | CPF0201D7K68C1_CPF0201D7K68C1 | CPF0201D7K68C1_0201 | 7.68k 0201 Thin Film Surface Mount Fixed Resistor +/-0.5% 0.031W CPF0201D7K68C1
SJ1 |  | ESP32_C6_LIBRARY_7_JUMPER_SJ | ESP32_C6_LIBRARY_7_JUMPER_SJ | SMD solder JUMPER |  |  |  |  |  |  |  |  |  |  |  |  |  |  |  |  |  |  |  | 3
SW1 | 2025-10-22_07-23-44_LIBRARY_EVP-AKE31ASW_EVP-AKE31A_PAN | 2025-10-22_07-23-44_LIBRARY_EVP-AKE31ASW_EVP-AKE31A_PAN | 2025-10-22_07-23-44_LIBRARY_SW_EVP-AKE31A_PAN |  |  |  |  |  | Copyright (C) 2025 Ultra Librarian. All rights reserved. |  | P123437TR-ND | P123437CT-ND | P123437DKR-ND |  |  | Panasonic | EVP-AKE31A
SW2 | 2025-10-22_07-23-44_LIBRARY_EVP-AKE31ASW_EVP-AKE31A_PAN | 2025-10-22_07-23-44_LIBRARY_EVP-AKE31ASW_EVP-AKE31A_PAN | 2025-10-22_07-23-44_LIBRARY_SW_EVP-AKE31A_PAN |  |  |  |  |  | Copyright (C) 2025 Ultra Librarian. All rights reserved. |  | P123437TR-ND | P123437CT-ND | P123437DKR-ND |  |  | Panasonic | EVP-AKE31A
SW3 | 2025-10-22_07-23-44_LIBRARY_EVP-AKE31ASW_EVP-AKE31A_PAN | 2025-10-22_07-23-44_LIBRARY_EVP-AKE31ASW_EVP-AKE31A_PAN | 2025-10-22_07-23-44_LIBRARY_SW_EVP-AKE31A_PAN |  |  |  |  |  | Copyright (C) 2025 Ultra Librarian. All rights reserved. |  | P123437TR-ND | P123437CT-ND | P123437DKR-ND |  |  | Panasonic | EVP-AKE31A
TP_3.3V | HECTOR_WATCH_1_TPTP20R | HECTOR_WATCH_1_TPTP20R | HECTOR_WATCH_1_TP20R | Test pad |  |  |  |  |  |  |  |  |  |  |  |  |  |  |  |  |  |  |  | 2
TP_3V3 | HECTOR_WATCH_1_TPTP20R | HECTOR_WATCH_1_TPTP20R | HECTOR_WATCH_1_TP20R | Test pad |  |  |  |  |  |  |  |  |  |  |  |  |  |  |  |  |  |  |  | 2
TP_BA_GND | HECTOR_WATCH_1_TPTP20R | HECTOR_WATCH_1_TPTP20R | HECTOR_WATCH_1_TP20R | Test pad |  |  |  |  |  |  |  |  |  |  |  |  |  |  |  |  |  |  |  | 2
TP_GND | HECTOR_WATCH_1_TPTP20R | HECTOR_WATCH_1_TPTP20R | HECTOR_WATCH_1_TP20R | Test pad |  |  |  |  |  |  |  |  |  |  |  |  |  |  |  |  |  |  |  | 2
TP_ON | HECTOR_WATCH_1_TPTP20R | HECTOR_WATCH_1_TPTP20R | HECTOR_WATCH_1_TP20R | Test pad |  |  |  |  |  |  |  |  |  |  |  |  |  |  |  |  |  |  |  | 2
TP_OP | HECTOR_WATCH_1_TPTP20R | HECTOR_WATCH_1_TPTP20R | HECTOR_WATCH_1_TP20R | Test pad |  |  |  |  |  |  |  |  |  |  |  |  |  |  |  |  |  |  |  | 2
TP_RESET | HECTOR_WATCH_1_TPTP20R | HECTOR_WATCH_1_TPTP20R | HECTOR_WATCH_1_TP20R | Test pad |  |  |  |  |  |  |  |  |  |  |  |  |  |  |  |  |  |  |  | 2
TP_SCL | HECTOR_WATCH_1_TPTP20R | HECTOR_WATCH_1_TPTP20R | HECTOR_WATCH_1_TP20R | Test pad |  |  |  |  |  |  |  |  |  |  |  |  |  |  |  |  |  |  |  | 2
TP_SDA | HECTOR_WATCH_1_TPTP20R | HECTOR_WATCH_1_TPTP20R | HECTOR_WATCH_1_TP20R | Test pad |  |  |  |  |  |  |  |  |  |  |  |  |  |  |  |  |  |  |  | 2
TP_SWDCLK | HECTOR_WATCH_1_TPTP20R | HECTOR_WATCH_1_TPTP20R | HECTOR_WATCH_1_TP20R | Test pad |  |  |  |  |  |  |  |  |  |  |  |  |  |  |  |  |  |  |  | 2
TP_SWDIO | HECTOR_WATCH_1_TPTP20R | HECTOR_WATCH_1_TPTP20R | HECTOR_WATCH_1_TP20R | Test pad |  |  |  |  |  |  |  |  |  |  |  |  |  |  |  |  |  |  |  | 2
TP_SWO | HECTOR_WATCH_1_TPTP20R | HECTOR_WATCH_1_TPTP20R | HECTOR_WATCH_1_TP20R | Test pad |  |  |  |  |  |  |  |  |  |  |  |  |  |  |  |  |  |  |  | 2
TP_VBAT | HECTOR_WATCH_1_TPTP20R | HECTOR_WATCH_1_TPTP20R | HECTOR_WATCH_1_TP20R | Test pad |  |  |  |  |  |  |  |  |  |  |  |  |  |  |  |  |  |  |  | 2
TP_VREG | HECTOR_WATCH_1_TPTP20R | HECTOR_WATCH_1_TPTP20R | HECTOR_WATCH_1_TP20R | Test pad |  |  |  |  |  |  |  |  |  |  |  |  |  |  |  |  |  |  |  | 2
U1 | NRF52840_QF | NORDIC_NRF_4_NRF52840_QF | NORDIC_NRF_4_AQFN50P700X700X85_HS-74N | nRF52840
U3 | MAX17048G+T10 | ESP32_C6_LIBRARY_MAX17048G+T10 | ESP32_C6_LIBRARY_SON50P200X200X80-9N | Check availability |  |  | In Stock | https://www.snapeda.com/parts/MAX17048G+T10/Analog+Devices/view-part/?ref=eda |  | 3µA 1-Cell/2-Cell Fuel Gauge with ModelGauge |  |  |  |  |  |  |  | Analog Devices |  |  |  | MAX17048G+T10 | TDFN-8 Maxim |  | None |  | https://www.snapeda.com/api/url_track_click_mouser/?unipart_id=329239&manufacturer=Analog Devices&part_name=MAX17048G+T10&search_term=None | https://www.snapeda.com/parts/MAX17048G+T10/Analog+Devices/view-part/?ref=snap
X1 | 32MHz | NORDIC_NRF_XTAL_32MHZ | NORDIC_NRF_BT-XTAL_2016_N
X2 | 32.768kHz | NORDIC_NRF_1_XTAL_32KHZ | NORDIC_NRF_1_XTAL_3215_N

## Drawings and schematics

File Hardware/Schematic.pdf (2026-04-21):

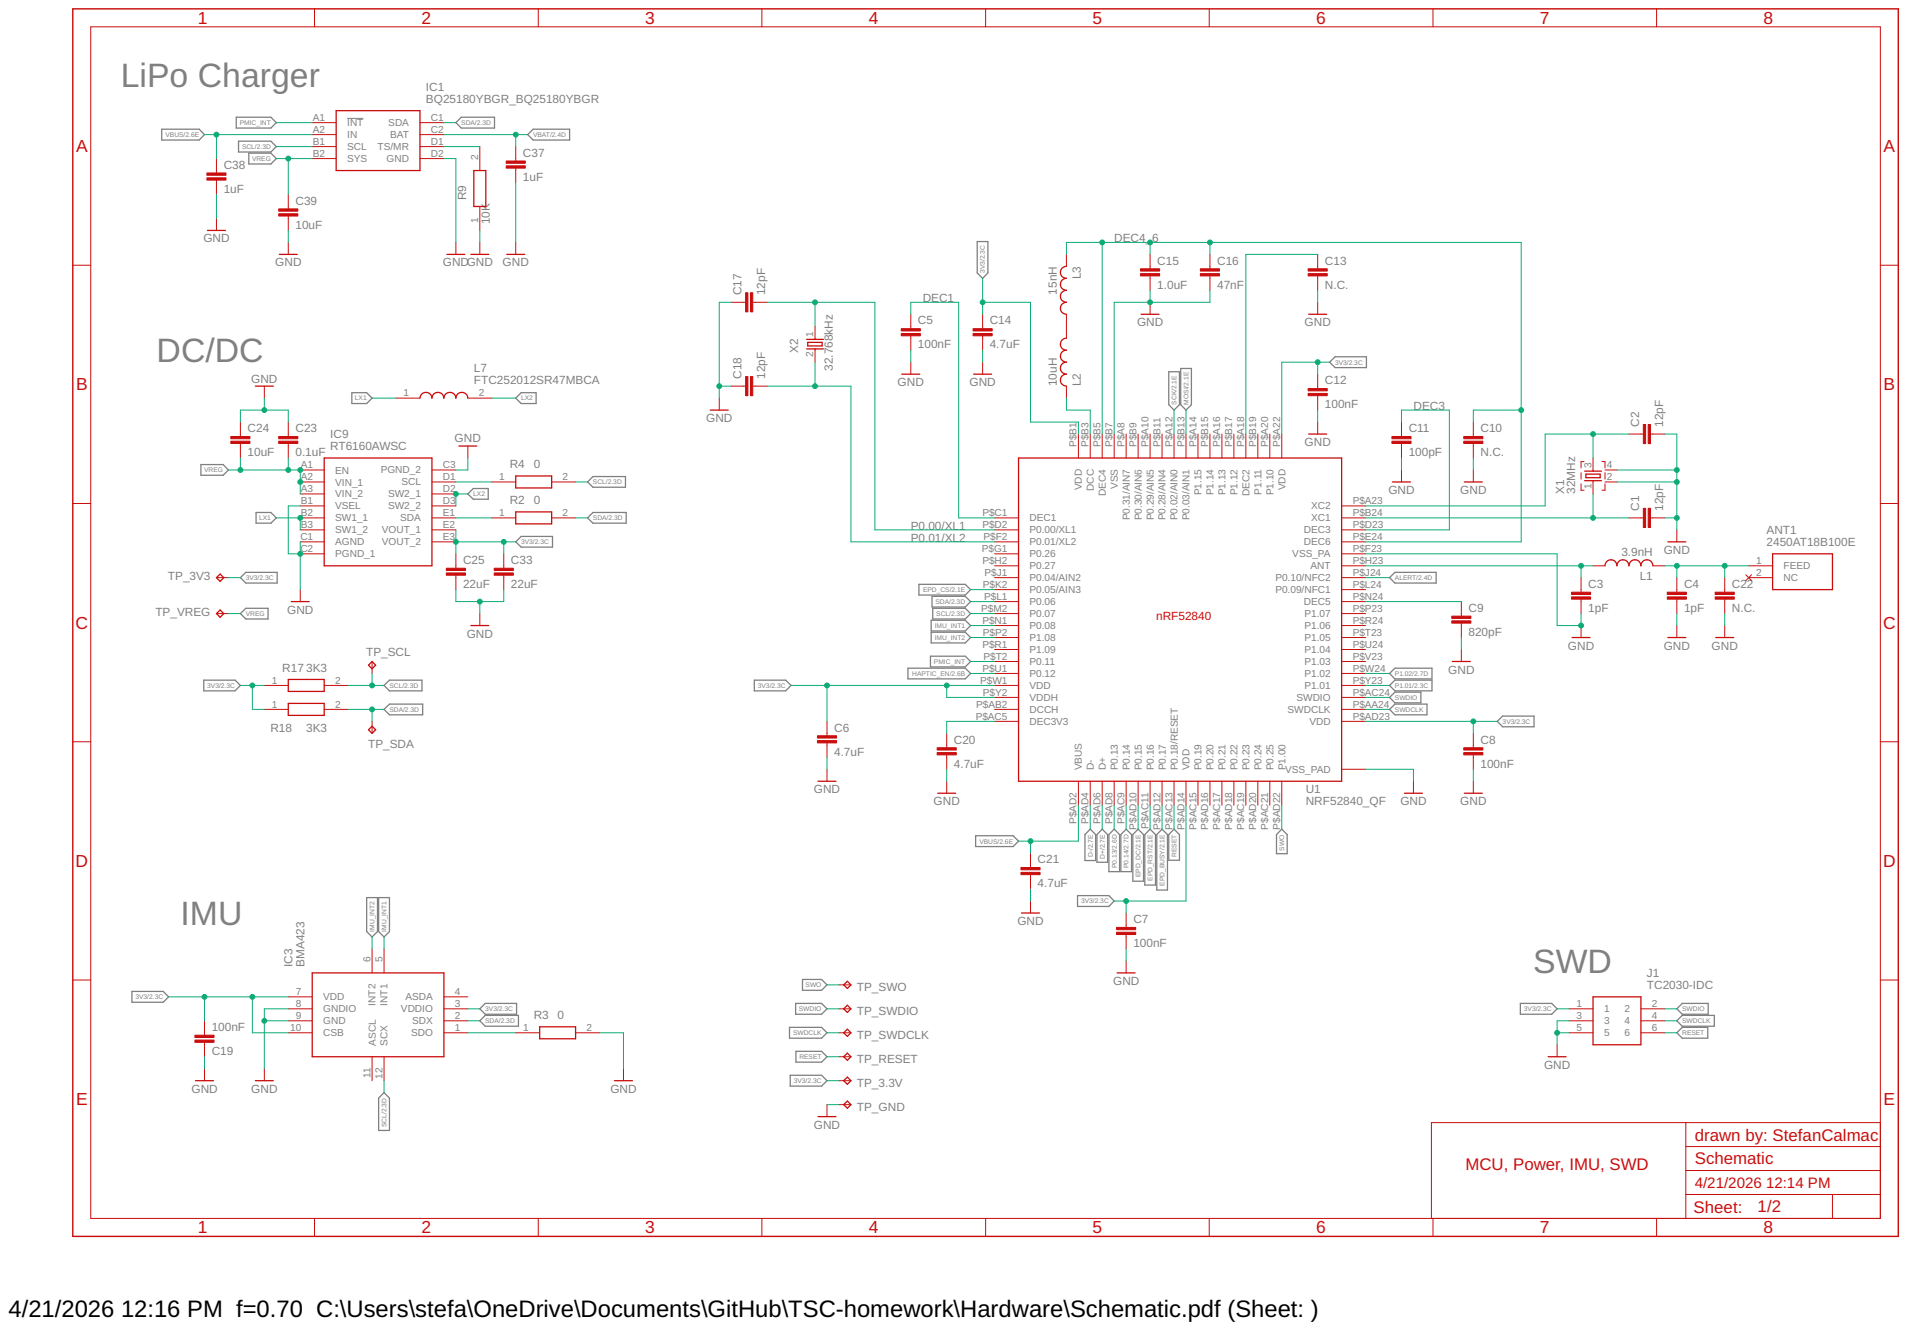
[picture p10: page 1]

SCL/2.3D | D2

drawn by: StefanCalmac Sheet:
Schematic

MCU, Power, IMU, SWD

4/21/2026 12:16 PM f=0.70 C:\Users\stefa\OneDrive\Documents\GitHub\TSC-homework\Hardware\Schematic.pdf (Sheet: )

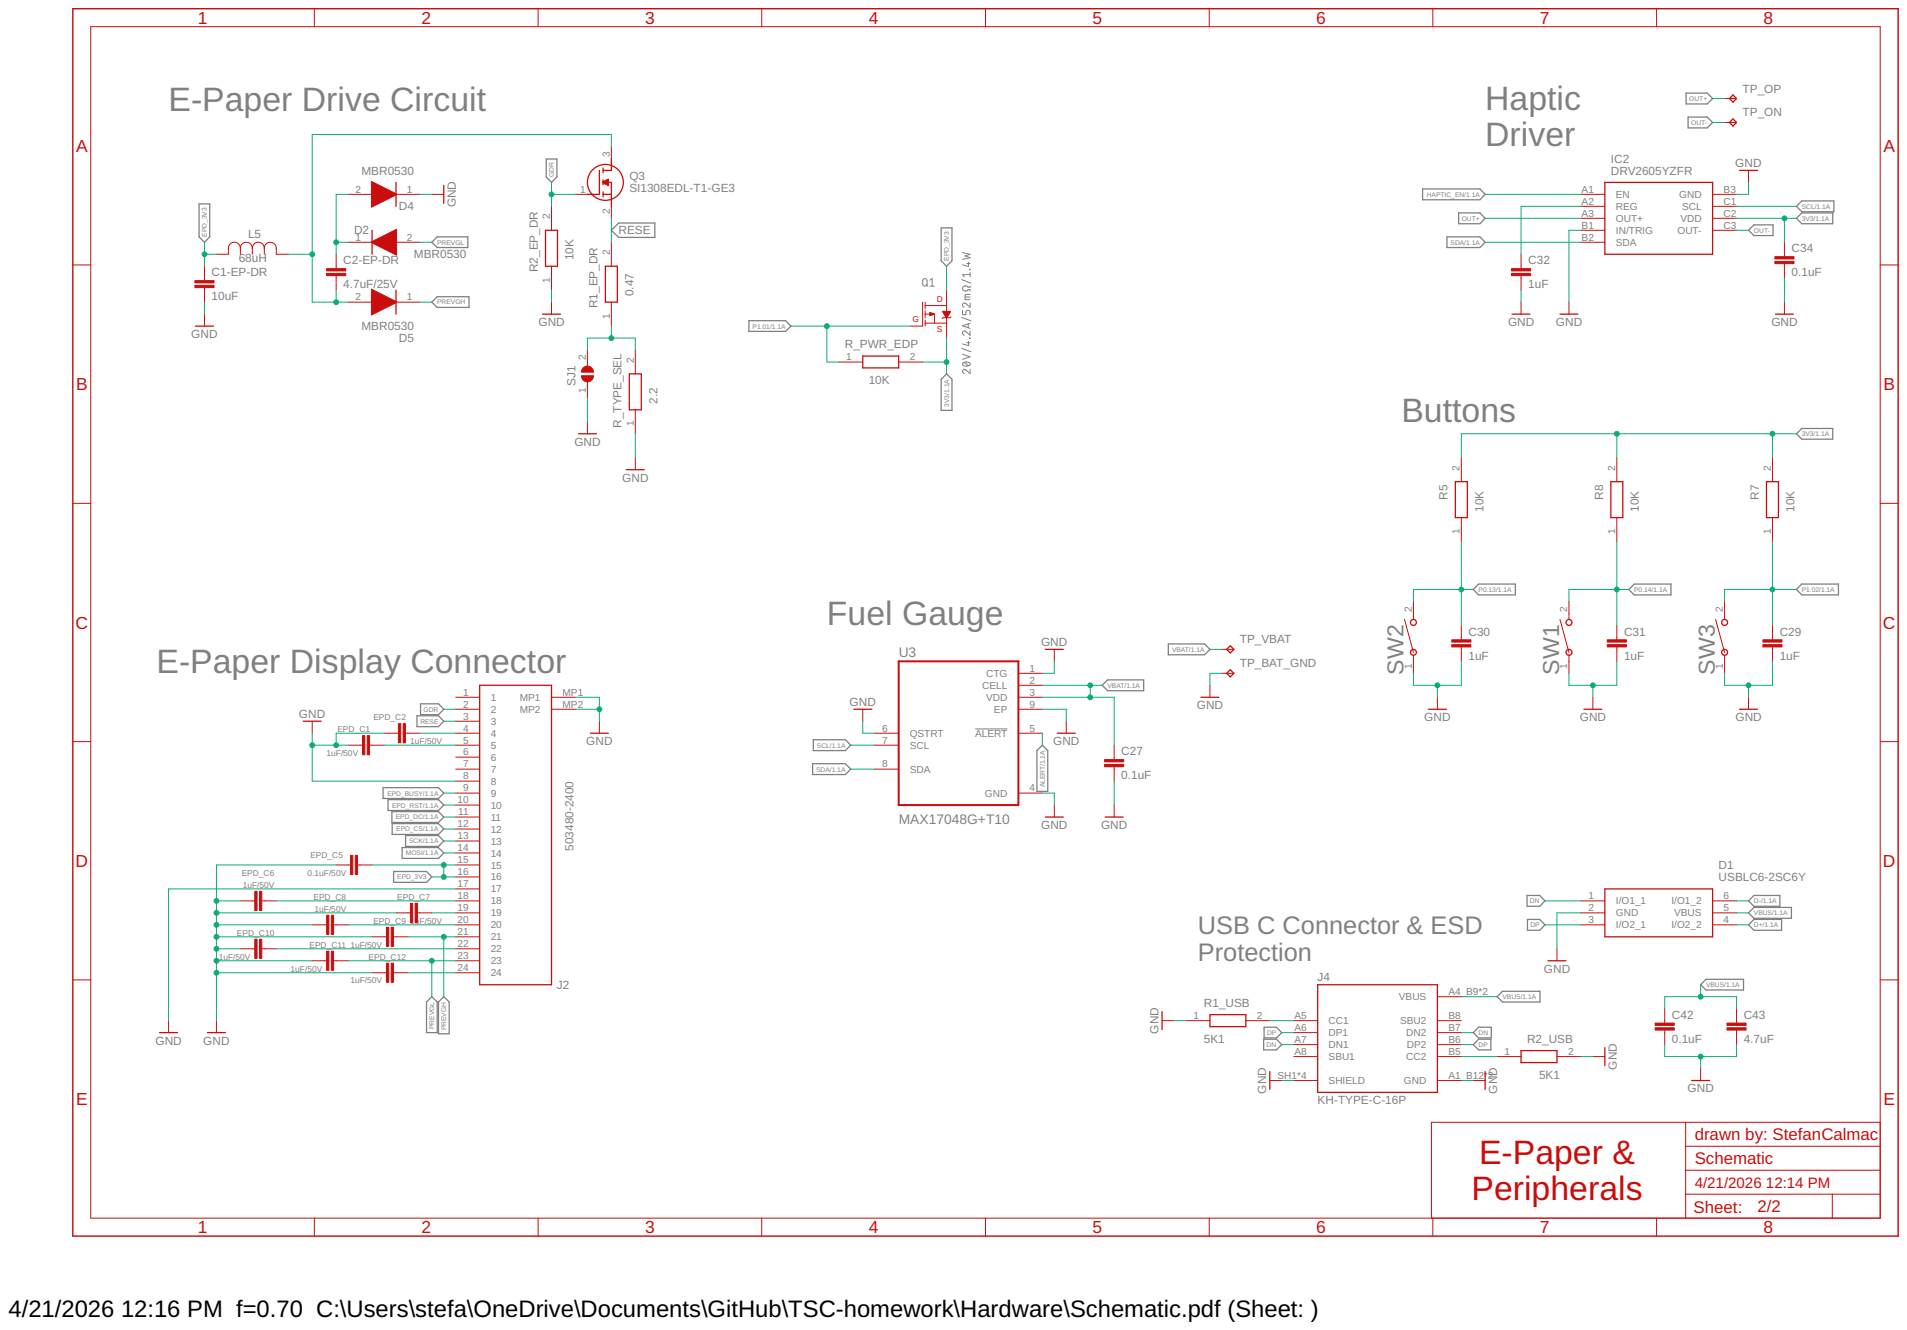
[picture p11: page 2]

HAPTIC_EN/1.1A | B3 SCL C1 VDD

E-Paper & | drawn by: StefanCalmac Peripherals

Sheet: 2/2

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

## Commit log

2026-03-15 Schematic first try
    [inktimev6.sch]
2026-04-10 Added files for review
    [InkTime.brd, PnP_InkTime_front.csv, Schematic.sch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]
2026-04-16 Update 2d pcb
    [InkTime.brd]
2026-04-19 Update PCB
    [Schematic.sch]
2026-04-20 Add PCB design, manufacturing files and docs
    [PnP_InkTime_front.csv, Schematic.sch]
2026-04-21 Add PCB design photos to README
    Added images of the PCB layers and 3D view to the README.
2026-04-21 Update 3D PCB image in README
